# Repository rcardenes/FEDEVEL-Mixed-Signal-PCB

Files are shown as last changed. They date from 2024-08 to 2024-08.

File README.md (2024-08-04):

Mixed-Signal Demo PCB
=====================

Demo board project for the "Mixed-Signal Hardware Design with KiCAD" course, by
Phil Salmony (of Phil's Lab fame) at [FEDEVEL](fedevel.com). 

The project was created from scratch using KiCAD 8.0, following the course lectures.
It comes with all the relevant files, including missing footprints and 3D models.
Several of the 3D models were downloaded, and are not to be used without permission:

- HRO_TYPE-C-31-M-12.step (USB receptacle, from GrabCad.com)
- 31-5640-1010.stp (BNC connectors, from Amphenol.com)
- L_Coilcraft_XxL4020.step (for the matching inductor, from 3DContentCentral.com)

The models for the CMF3216 common-mode choke, and the RGB LED (E6C...) were created
by myself in FreeCAD and are free to use, with appropriate acknowledgment.

The project includes Gerber files, and BOM/Placement files. All relevant parts include
an MNP field with JCLPCB/LCSC part numbers, and the assembly files were generated using
the "Fabrication Toolkit" plugin, which generates JLCPCB-compatible output.

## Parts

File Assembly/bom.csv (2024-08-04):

Designator | Footprint | Quantity | Value | LCSC Part #
C201, C302, C303, C304, C305, C311, C312, C313, C402, C403, C404, C410, C411, C416, C503, C504 | 0402 | 16 | 100n | C1525
C202, C203, C307, C308, C507 | 0603 | 5 | 1u | C15849
C204, C205, C206, C207, C208 | 0805 | 5 | 22u | C45783
C209 | 0402 | 1 | DNP
C301, C409, C412, C413, C414, C415, C502 | 0603 | 7 | 10u | C19702
C306 | 0402 | 1 | 10nF | C15195
C309, C310 | 0402 | 2 | 10p | C32949
C401, C406, C501, C505 | 0402 | 4 | 1n | C1523
C405, C407, C408, C506 | 0402 | 4 | 150p | C106998
D201 | 0603 | 1 | RED | C2286
D301 | E6C1206RGBC3UDA | 1 | LED_RGB_E6C1206RGBC3UDA | C375571
D302, D303, D304, D305, D306, D401, D501 | D_SOD-323 | 7 | PESD3V3L1BA,115 | C51450
FL301 | CMF3216F | 1 | CMF3216F-900-2P-T | C963740
J301 | USB_C_Receptacle_HRO_TYPE-C-31-M-12 | 1 | USB_C_Receptacle_USB2.0_16P | C319148
J302 | PinHeader_2x05_P1.27mm_Vertical_SMD | 1 | 2x5x1.27mm | C920813
J401, J501 | BNC_Amphenol_B6252HB-NPP3G-50_Horizontal | 2 | DOSIN-801-0031 | C521205
L201, L301 | 0402 | 2 | 10n | C404632
L202 | L_Coilcraft_XxL4020 | 1 | 68u | C3151182
R201 | 0805 | 1 | 10R | C17415
R202, R203, R205, R308, R310, R313, R402, R406, R408 | 0402 | 9 | 1k | C11702
R204 | 0402 | 1 | 100k | 0402
R206, R404, R502 | 0402 | 3 | 22k | C25768
R301, R302, R307, R506 | 0402 | 4 | 10k | C25744
R303, R304 | 0402 | 2 | 5k1 | C25905
R305, R410, R505 | 0402 | 3 | 0R | C17168
R306 | 0402 | 1 | 1k5 | C25867
R309, R311, R312, R314, R409, R504 | 0402 | 6 | 49R9 | C25120
R401, R407 | 0402 | 2 | 2M2 | C274901
R403, R501 | 0603 | 2 | 6k8 | C23212
R405, R503 | 0402 | 2 | 12k | C25752
U201 | SOT-89-3 | 1 | HT7533-1 | C14289
U202, U401, U402, U501 | SOT-23-5 | 4 | MCP6001T-E/OT | C29429
U203 | SOT-23-5 | 1 | TLV62569DBV | C2864104
U301 | LQFP-48_7x7mm_P0.5mm | 1 | STM32F103CBT6 | C8304
U302 | SOT-23-6 | 1 | USBLC6-2SC6 | USBLC6-2SC6
U403 | VSSOP-10_3x3mm_P0.5mm | 1 | ADC141S626CIMM_NOPB | C206494
U404 | SOT-23 | 1 | REF3033A/DBZT | C2872391
U502 | VSSOP-10_3x3mm_P0.5mm | 1 | DAC7563TDGSR | C2879196
Y301 | Crystal_SMD_3225-4Pin_3.2x2.5mm | 1 | 16MHz | C362342

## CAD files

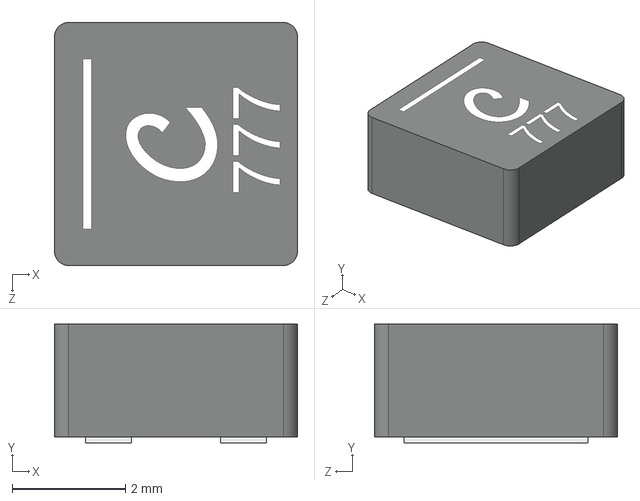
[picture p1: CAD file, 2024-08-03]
3DModels/3DContentCentral/L_Coilcraft_XxL4020.step
4.30 x 2.10 x 4.30 mm

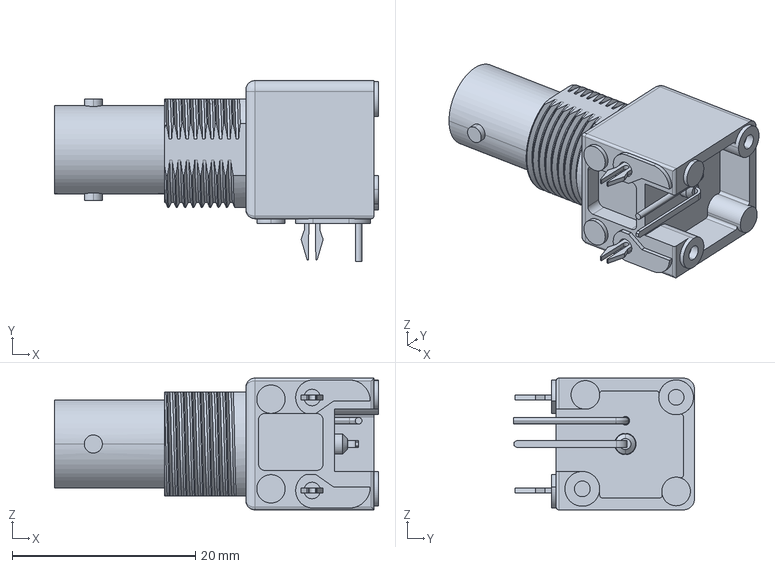
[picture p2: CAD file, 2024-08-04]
3DModels/Amphenol/31-5640-1010.stp
35.4 x 19.8 x 14.4 mm

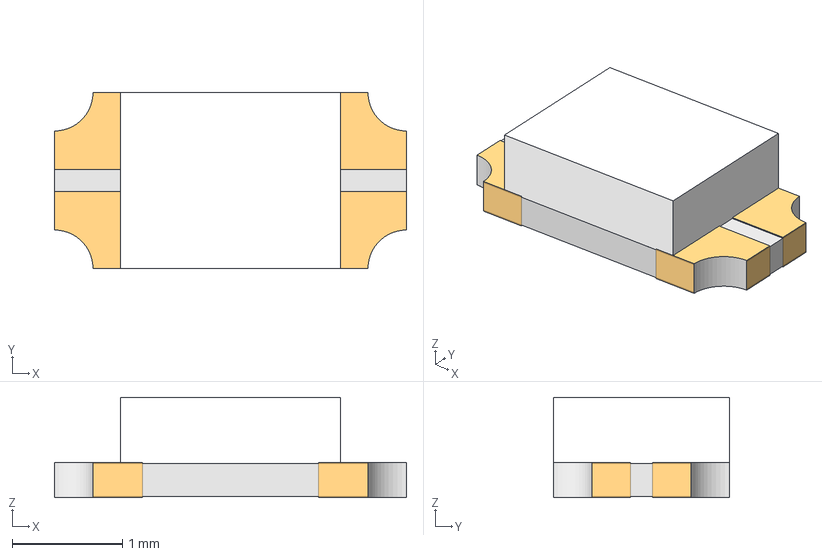
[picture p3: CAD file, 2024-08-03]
3DModels/E6C1206RGBC3UDA.step
3.20 x 1.60 x 0.91 mm

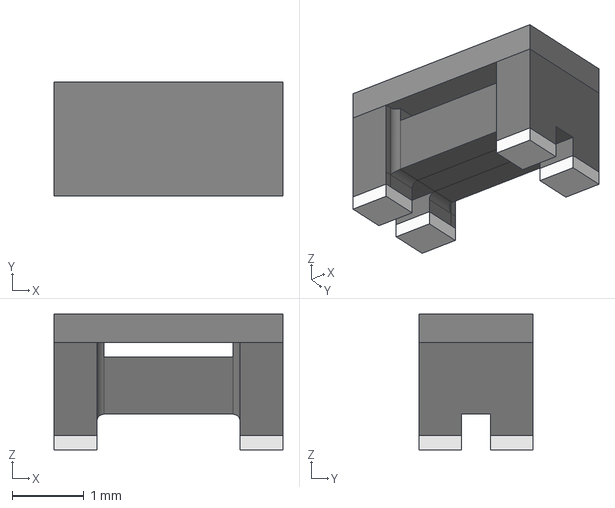
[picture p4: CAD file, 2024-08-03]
3DModels/CMF3216.step
3.20 x 1.60 x 1.90 mm

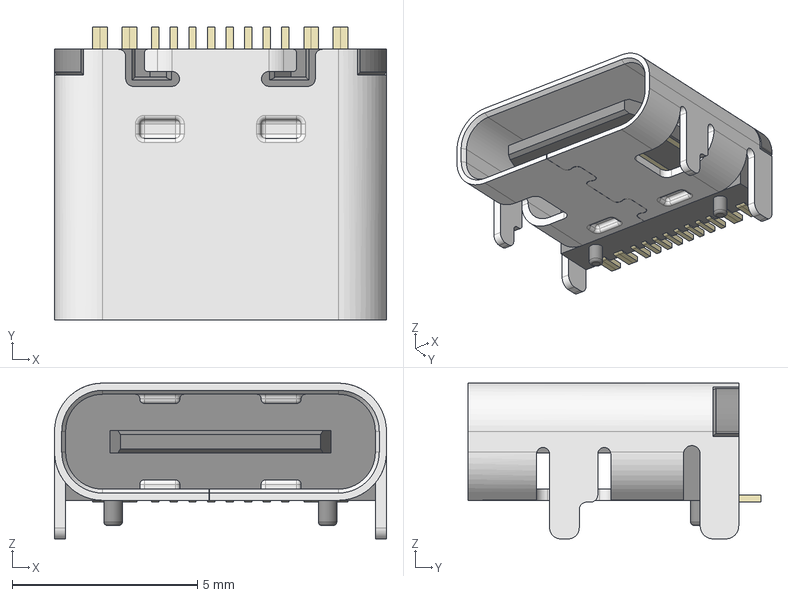
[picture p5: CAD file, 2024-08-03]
3DModels/GrabCad/HRO_TYPE-C-31-M-12.step
8.95 x 7.90 x 4.20 mm

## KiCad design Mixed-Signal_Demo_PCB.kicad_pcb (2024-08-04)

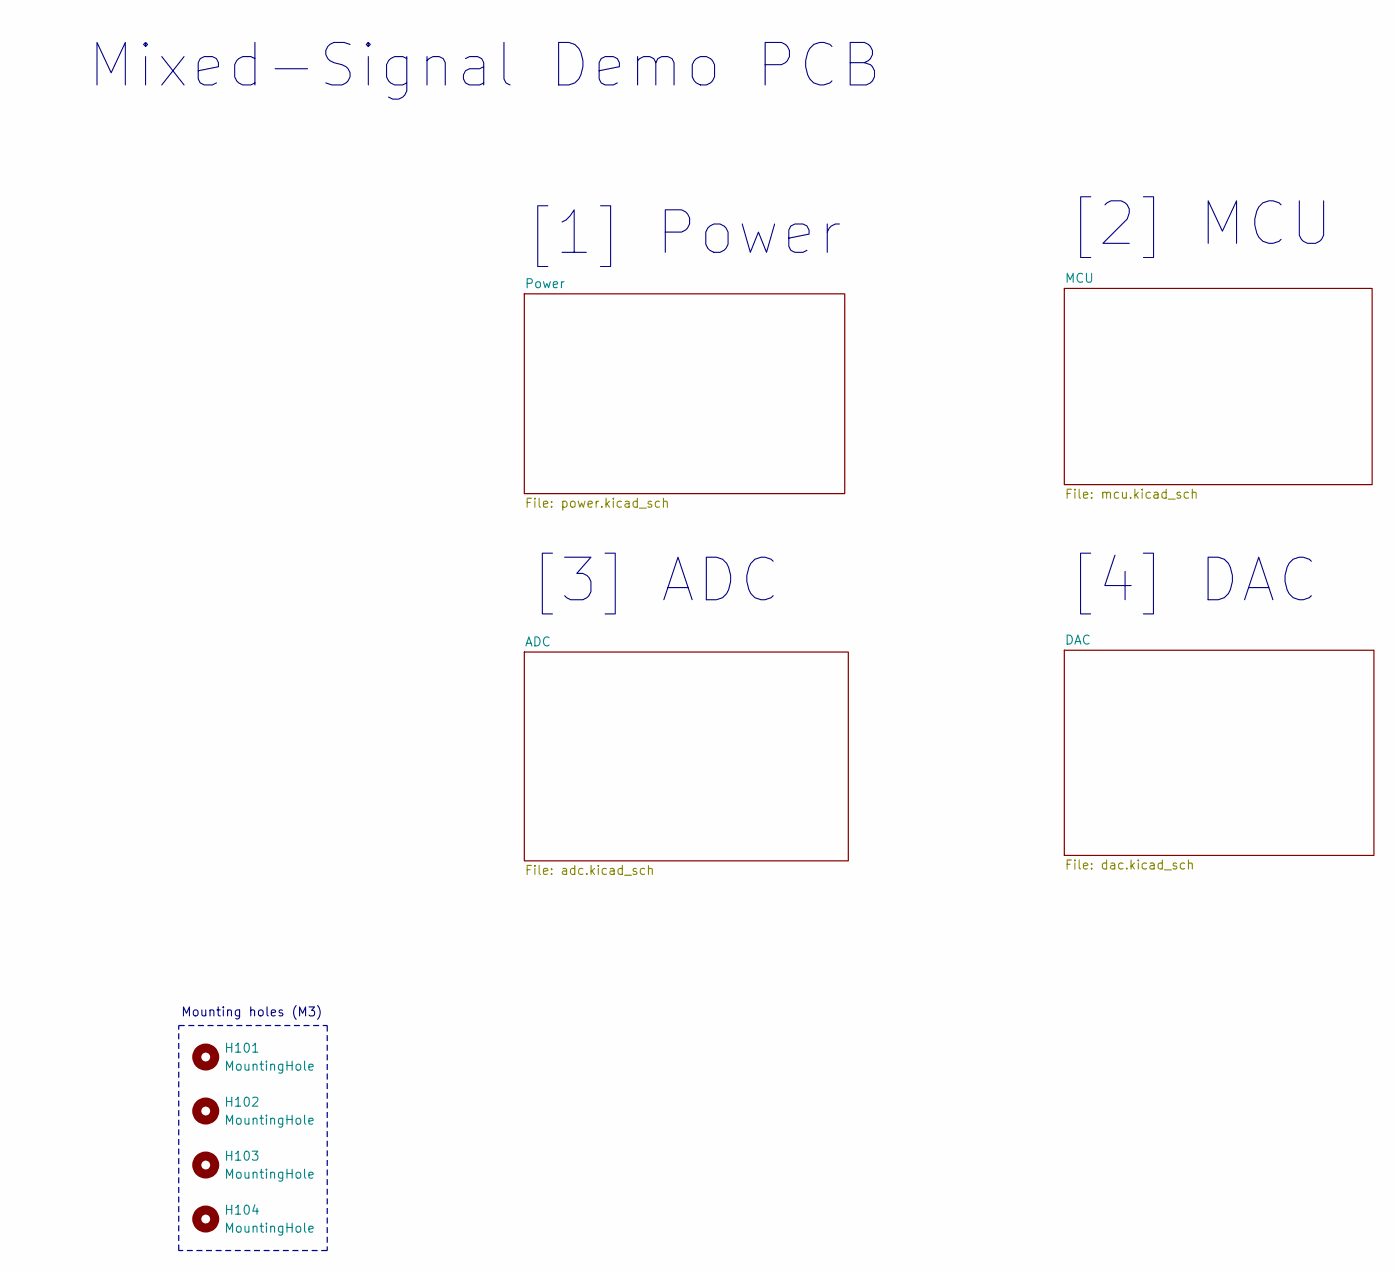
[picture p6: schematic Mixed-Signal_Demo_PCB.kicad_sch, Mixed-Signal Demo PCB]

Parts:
H101, H102, H103, H104: MountingHole; MountingHole_3.2mm_M3

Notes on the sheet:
[2] MCU
[1] Power
[3] ADC
[4] DAC
Mounting holes (M3)
Mixed-Signal Demo PCB

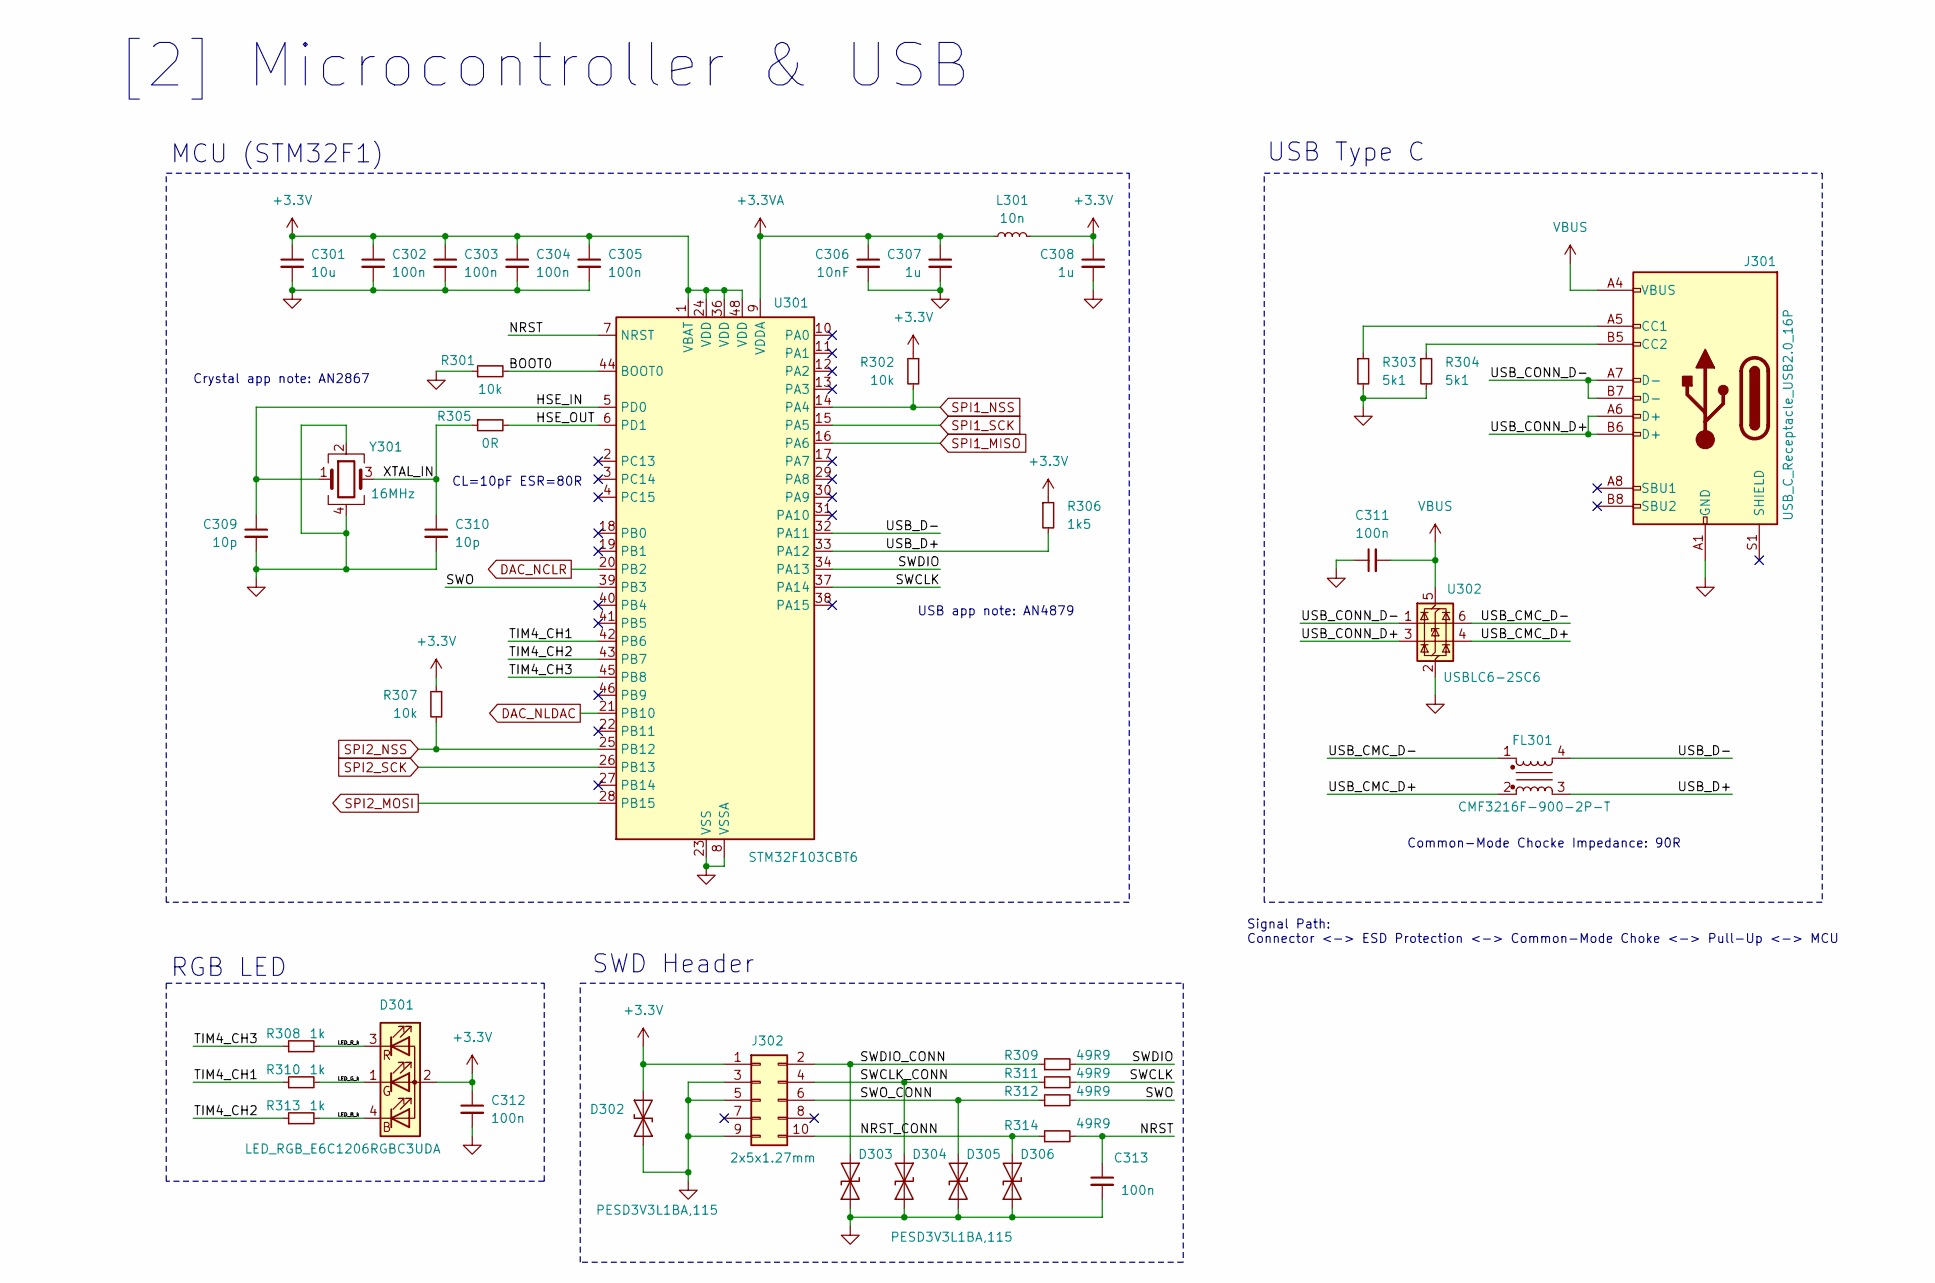
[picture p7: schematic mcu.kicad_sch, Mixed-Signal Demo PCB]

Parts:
C301: 10u; C_0603_1608Metric; MPN C19702
C302, C303, C304, C305, C311, C312, C313: 100n; C_0402_1005Metric; MPN C1525
C306: 10nF; C_0402_1005Metric; MPN C15195
C307, C308: 1u; C_0603_1608Metric; MPN C15849
C309, C310: 10p; C_0402_1005Metric; MPN C32949
D301: LED_RGB_E6C1206RGBC3UDA; E6C1206RGBC3UDA; MPN C375571
D302, D303, D304, D305, D306: PESD3V3L1BA,115; D_SOD-323; MPN C51450
FL301: CMF3216F-900-2P-T; CMF3216F; MPN C963740
J301: USB_C_Receptacle_USB2.0_16P; USB_C_Receptacle_HRO_TYPE-C-31-M-12; MPN C319148
J302: 2x5x1.27mm; PinHeader_2x05_P1.27mm_Vertical_SMD; MPN C920813
L301: 10n; L_0402_1005Metric; MPN C404632
R301, R302, R307: 10k; R_0402_1005Metric; MPN C25744
R303, R304: 5k1; R_0402_1005Metric; MPN C25905
R305: 0R; R_0402_1005Metric; MPN C17168
R306: 1k5; R_0402_1005Metric; MPN C25867
R308, R310, R313: 1k; R_0402_1005Metric; MPN C11702
R309, R311, R312, R314: 49R9; R_0402_1005Metric; MPN C25120
U301: STM32F103CBT6; LQFP-48_7x7mm_P0.5mm; MPN C8304
U302: USBLC6-2SC6; SOT-23-6; MPN USBLC6-2SC6
Y301: 16MHz; Crystal_SMD_3225-4Pin_3.2x2.5mm; MPN C362342

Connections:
+3.3V: C301.1, C302.1, C303.1, C304.1, C305.1, C308.1, C312.1, D301.2 (A), D302.2 (A2), J302.1, L301.2, R302.1, R306.1, R307.1, U301.1 (VBAT), U301.24 (VDD), U301.36 (VDD), U301.48 (VDD); also elsewhere on the board
+3.3VA: C306.1, C307.1, L301.1, U301.9 (VDDA); also elsewhere on the board
/MCU/BOOT0: R301.2, U301.44 (BOOT0)
/MCU/HSE_IN: C309.1, U301.5 (PD0), Y301.1
/MCU/HSE_OUT: R305.2, U301.6 (PD1)
/MCU/LED_B_k: D301.4 (BK), R313.2
/MCU/LED_G_k: D301.1 (GK), R310.2
/MCU/LED_R_k: D301.3 (RK), R308.2
/MCU/NRST: C313.1, R314.2, U301.7 (NRST)
/MCU/NRST_CONN: D306.2 (A2), J302.10, R314.1
/MCU/SWCLK: R311.2, U301.37 (PA14)
/MCU/SWCLK_CONN: D304.2 (A2), J302.4, R311.1
/MCU/SWDIO: R309.2, U301.34 (PA13)
/MCU/SWDIO_CONN: D303.2 (A2), J302.2, R309.1
/MCU/SWO: R312.2, U301.39 (PB3)
/MCU/SWO_CONN: D305.2 (A2), J302.6, R312.1
/MCU/TIM4_CH1: R310.1, U301.42 (PB6)
/MCU/TIM4_CH2: R313.1, U301.43 (PB7)
/MCU/TIM4_CH3: R308.1, U301.45 (PB8)
/MCU/USB_CMC_D+: FL301.2, U302.4 (I/O2)
/MCU/USB_CMC_D-: FL301.1, U302.6 (I/O1)
/MCU/USB_CONN_D+: J301.A6 (D+), J301.B6 (D+), U302.3 (I/O2)
/MCU/USB_CONN_D-: J301.A7 (D-), J301.B7 (D-), U302.1 (I/O1)
/MCU/USB_D+: FL301.3, R306.2, U301.33 (PA12)
/MCU/USB_D-: FL301.4, U301.32 (PA11)
/MCU/XTAL_IN: C310.1, R305.1, Y301.3
DAC_NCLR: U301.20 (PB2); also elsewhere on the board
DAC_NLDAC: U301.21 (PB10); also elsewhere on the board
GND: C301.2, C302.2, C303.2, C304.2, C305.2, C306.2, C307.2, C308.2, C309.2, C310.2, C311.1, C312.2, C313.2, D302.1 (A1), D303.1 (A1), D304.1 (A1), D305.1 (A1), D306.1 (A1), J301.A1 (GND), J301.A12 (GND), J301.B1 (GND), J301.B12 (GND), J302.3, J302.5, J302.9, R301.1, R303.2, R304.2, U301.8 (VSSA), U301.23 (VSS), U301.35 (VSS), U301.47 (VSS), U302.2 (GND), Y301.2, Y301.4; also elsewhere on the board
unnamed: J301.A5 (CC1), R303.1
unnamed: J301.B5 (CC2), R304.1
SPI1_MISO: U301.16 (PA6); also elsewhere on the board
SPI1_NSS: R302.2, U301.14 (PA4); also elsewhere on the board
SPI1_SCK: U301.15 (PA5); also elsewhere on the board
SPI2_MOSI: U301.28 (PB15); also elsewhere on the board
SPI2_NSS: R307.2, U301.25 (PB12); also elsewhere on the board
SPI2_SCK: U301.26 (PB13); also elsewhere on the board
VBUS: C311.2, J301.A4 (VBUS), J301.A9 (VBUS), J301.B4 (VBUS), J301.B9 (VBUS), U302.5 (VBUS); also elsewhere on the board

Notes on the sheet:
MCU (STM32F1)
[2] Microcontroller & USB
RGB LED
SWD Header
Crystal app note: AN2867
CL=10pF ESR=80R
Signal Path: Connector <-> ESD Protection <-> Common-Mode Choke <-> Pull-Up <-> MCU
USB app note: AN4879
Common-Mode Chocke Impedance: 90R
USB Type C

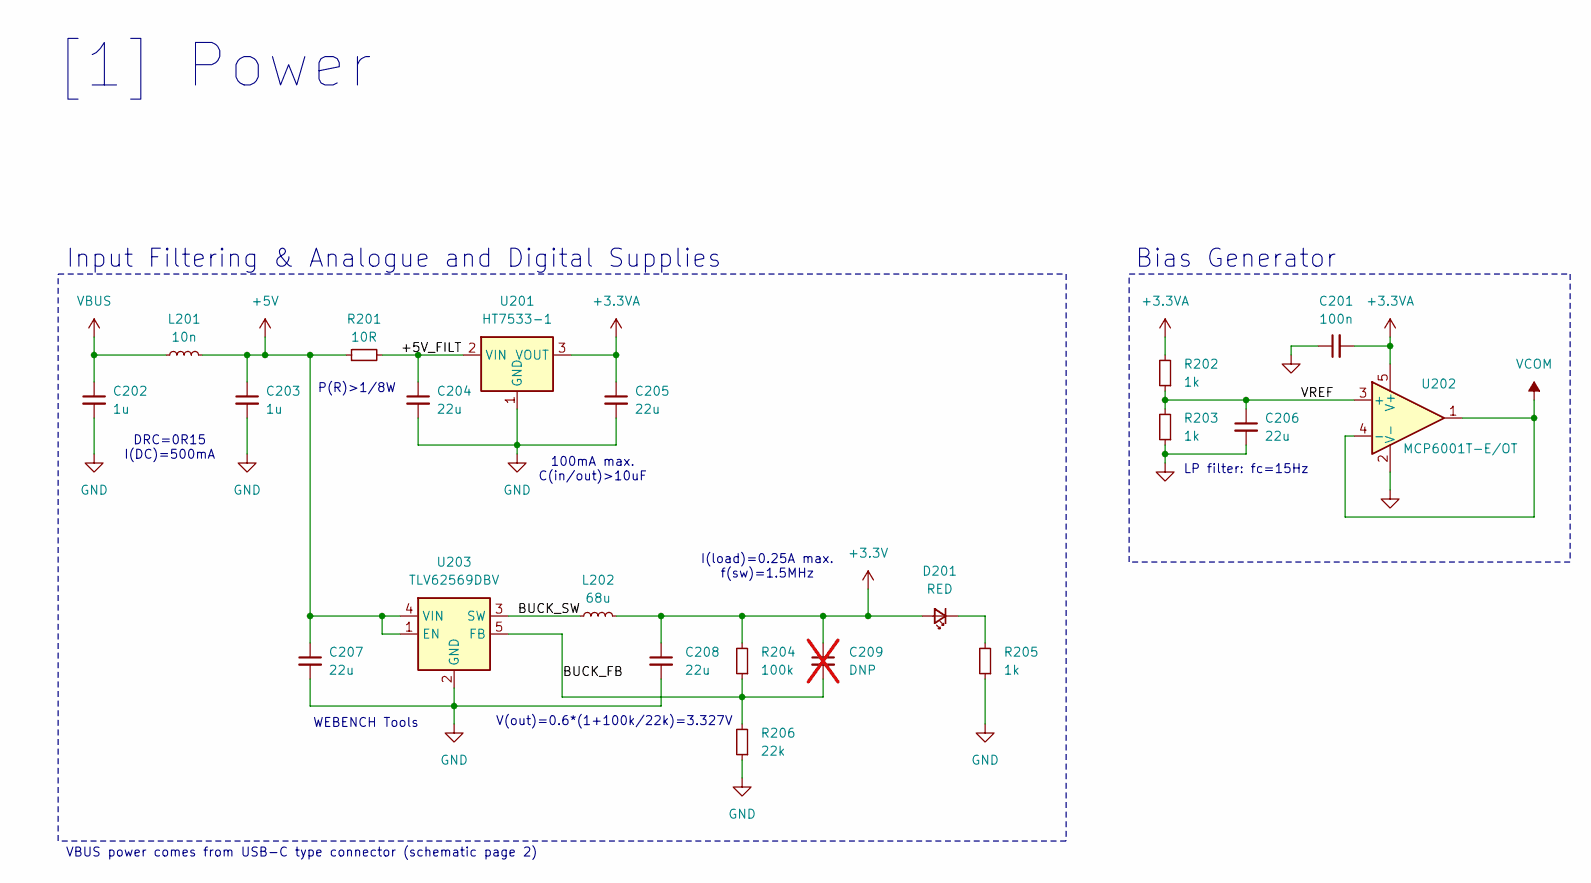
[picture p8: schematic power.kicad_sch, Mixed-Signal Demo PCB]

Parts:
C201: 100n; C_0402_1005Metric; MPN C1525
C202, C203: 1u; C_0603_1608Metric; MPN C15849
C204, C205, C206, C207, C208: 22u; C_0805_2012Metric; MPN C45783
C209: DNP; C_0402_1005Metric; not fitted
D201: RED; LED_0603_1608Metric; MPN C2286
L201: 10n; L_0402_1005Metric; MPN C404632
L202: 68u; L_Coilcraft_XxL4020; MPN C3151182
R201: 10R; R_0805_2012Metric; MPN C17415
R202, R203, R205: 1k; R_0402_1005Metric; MPN C11702
R204: 100k; R_0402_1005Metric; MPN 0402
R206: 22k; R_0402_1005Metric; MPN C25768
U201: HT7533-1; SOT-89-3; MPN C14289
U202: MCP6001T-E/OT; SOT-23-5; MPN C29429
U203: TLV62569DBV; SOT-23-5; MPN C2864104

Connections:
+3.3V: C208.1, C209.1, D201.2 (A), L202.2, R204.2; also elsewhere on the board
+3.3VA: C201.2, C205.1, R202.2, U201.3 (VOUT), U202.5 (V+); also elsewhere on the board
+5V: C203.1, C207.1, L201.2, R201.1, U203.1 (EN), U203.4 (VIN); also elsewhere on the board
/Power/+5V_FILT: C204.1, R201.2, U201.2 (VIN)
/Power/BUCK_FB: C209.2, R204.1, R206.2, U203.5 (FB)
/Power/BUCK_SW: L202.1, U203.3 (SW)
/Power/VREF: C206.1, R202.1, R203.2, U202.3 (+)
GND: C201.1, C202.2, C203.2, C204.2, C205.2, C206.2, C207.2, C208.2, R203.1, R205.1, R206.1, U201.1 (GND), U202.2 (V-), U203.2 (GND); also elsewhere on the board
unnamed: D201.1 (K), R205.2
VBUS: C202.1, L201.1; also elsewhere on the board
VCOM: U202.1, U202.4 (-); also elsewhere on the board

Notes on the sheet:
100mA max. C(in/out)>10uF
I(load)=0.25A max. f(sw)=1.5MHz
Bias Generator
DRC=0R15 I(DC)=500mA
P(R)>1/8W
LP filter: fc=15Hz
V(out)=0.6*(1+100k/22k)=3.327V
VBUS power comes from USB-C type connector (schematic page 2)
[1] Power
WEBENCH Tools
Input Filtering & Analogue and Digital Supplies

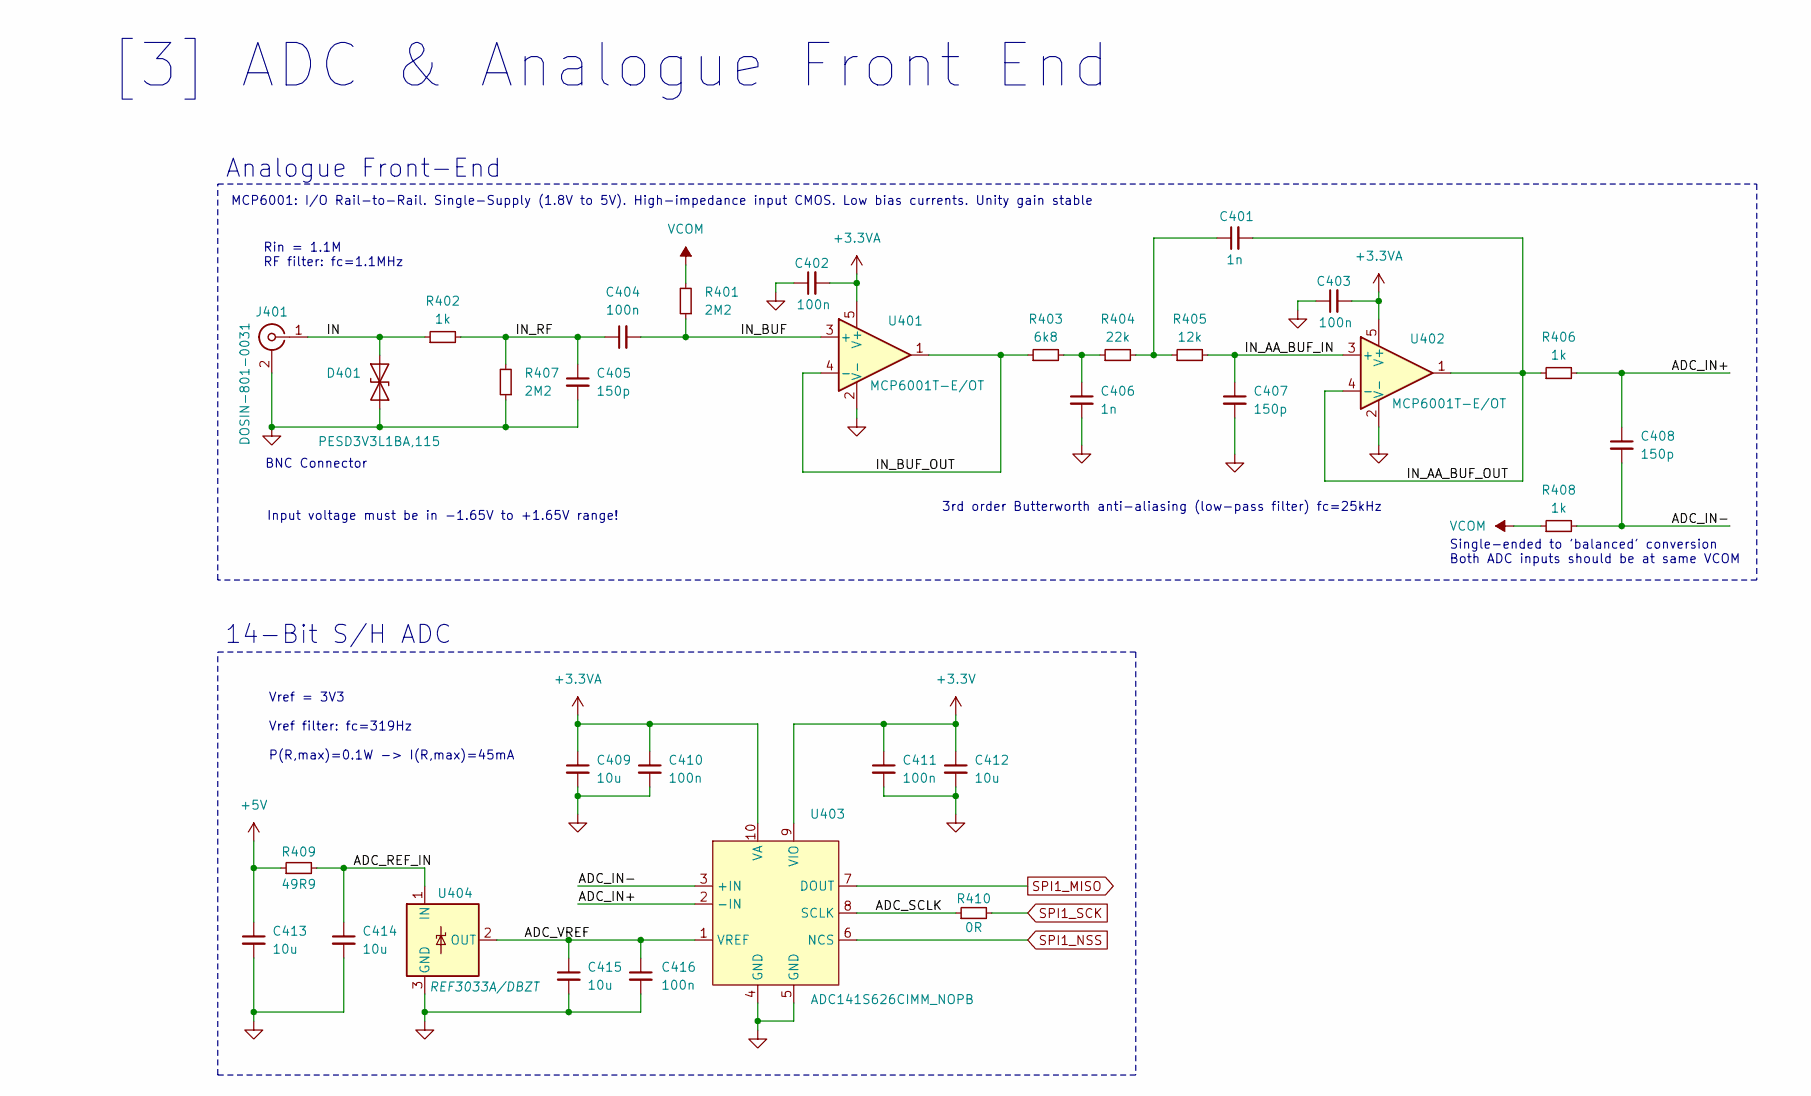
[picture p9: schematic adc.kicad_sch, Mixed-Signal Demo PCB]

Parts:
C401, C406: 1n; C_0402_1005Metric; MPN C1523
C402, C403, C404, C410, C411, C416: 100n; C_0402_1005Metric; MPN C1525
C405, C407, C408: 150p; C_0402_1005Metric; MPN C106998
C409, C412, C413, C414, C415: 10u; C_0603_1608Metric; MPN C19702
D401: PESD3V3L1BA,115; D_SOD-323; MPN C51450
J401: DOSIN-801-0031; BNC_Amphenol_B6252HB-NPP3G-50_Horizontal; MPN C521205
R401, R407: 2M2; R_0402_1005Metric; MPN C274901
R402, R406, R408: 1k; R_0402_1005Metric; MPN C11702
R403: 6k8; R_0603_1608Metric; MPN C23212
R404: 22k; R_0402_1005Metric; MPN C25768
R405: 12k; R_0402_1005Metric; MPN C25752
R409: 49R9; R_0402_1005Metric; MPN C25120
R410: 0R; R_0402_1005Metric; MPN C17168
U401, U402: MCP6001T-E/OT; SOT-23-5; MPN C29429
U403: ADC141S626CIMM_NOPB; VSSOP-10_3x3mm_P0.5mm; MPN C206494
U404: REF3033A/DBZT; SOT-23; MPN C2872391

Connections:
+3.3V: C411.1, C412.1, U403.9 (VIO); also elsewhere on the board
+3.3VA: C402.2, C403.2, C409.1, C410.1, U401.5 (V+), U402.5 (V+), U403.10 (VA); also elsewhere on the board
+5V: C413.1, R409.1; also elsewhere on the board
/ADC/ADC_IN+: C408.1, R406.2, U403.2 (-IN)
/ADC/ADC_IN-: C408.2, R408.2, U403.3 (+IN)
/ADC/ADC_REF_IN: C414.1, R409.2, U404.1 (IN)
/ADC/ADC_SCLK: R410.1, U403.8 (SCLK)
/ADC/ADC_VREF: C415.1, C416.1, U403.1 (VREF), U404.2 (OUT)
/ADC/IN: D401.2 (A2), J401.1 (In), R402.1
/ADC/IN_AA_BUF_IN: C407.1, R405.2, U402.3 (+)
/ADC/IN_AA_BUF_OUT: C401.2, R406.1, U402.1, U402.4 (-)
/ADC/IN_BUF: C404.2, R401.1, U401.3 (+)
/ADC/IN_BUF_OUT: R403.1, U401.1, U401.4 (-)
/ADC/IN_RF: C404.1, C405.1, R402.2, R407.2
GND: C402.1, C403.1, C405.2, C406.2, C407.2, C409.2, C410.2, C411.2, C412.2, C413.2, C414.2, C415.2, C416.2, D401.1 (A1), J401.2 (Ext), R407.1, U401.2 (V-), U402.2 (V-), U403.4 (GND), U403.5 (GND), U404.3 (GND); also elsewhere on the board
unnamed: C401.1, R404.2, R405.1
unnamed: C406.1, R403.2, R404.1
SPI1_MISO: U403.7 (DOUT); also elsewhere on the board
SPI1_NSS: U403.6 (NCS); also elsewhere on the board
SPI1_SCK: R410.2; also elsewhere on the board
VCOM: R401.2, R408.1; also elsewhere on the board

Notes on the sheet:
[3] ADC & Analogue Front End
MCP6001: I/O Rail-to-Rail. Single-Supply (1.8V to 5V). High-impedance input CMOS. Low bias currents. Unity gain stable
Input voltage must be in -1.65V to +1.65V range!
Analogue Front-End
3rd order Butterworth anti-aliasing (low-pass filter) fc=25kHz
Single-ended to 'balanced' conversion Both ADC inputs should be at same VCOM
Rin = 1.1M RF filter: fc=1.1MHz
BNC Connector
14-Bit S/H ADC
Vref = 3V3 Vref filter: fc=319Hz P(R,max)=0.1W -> I(R,max)=45mA

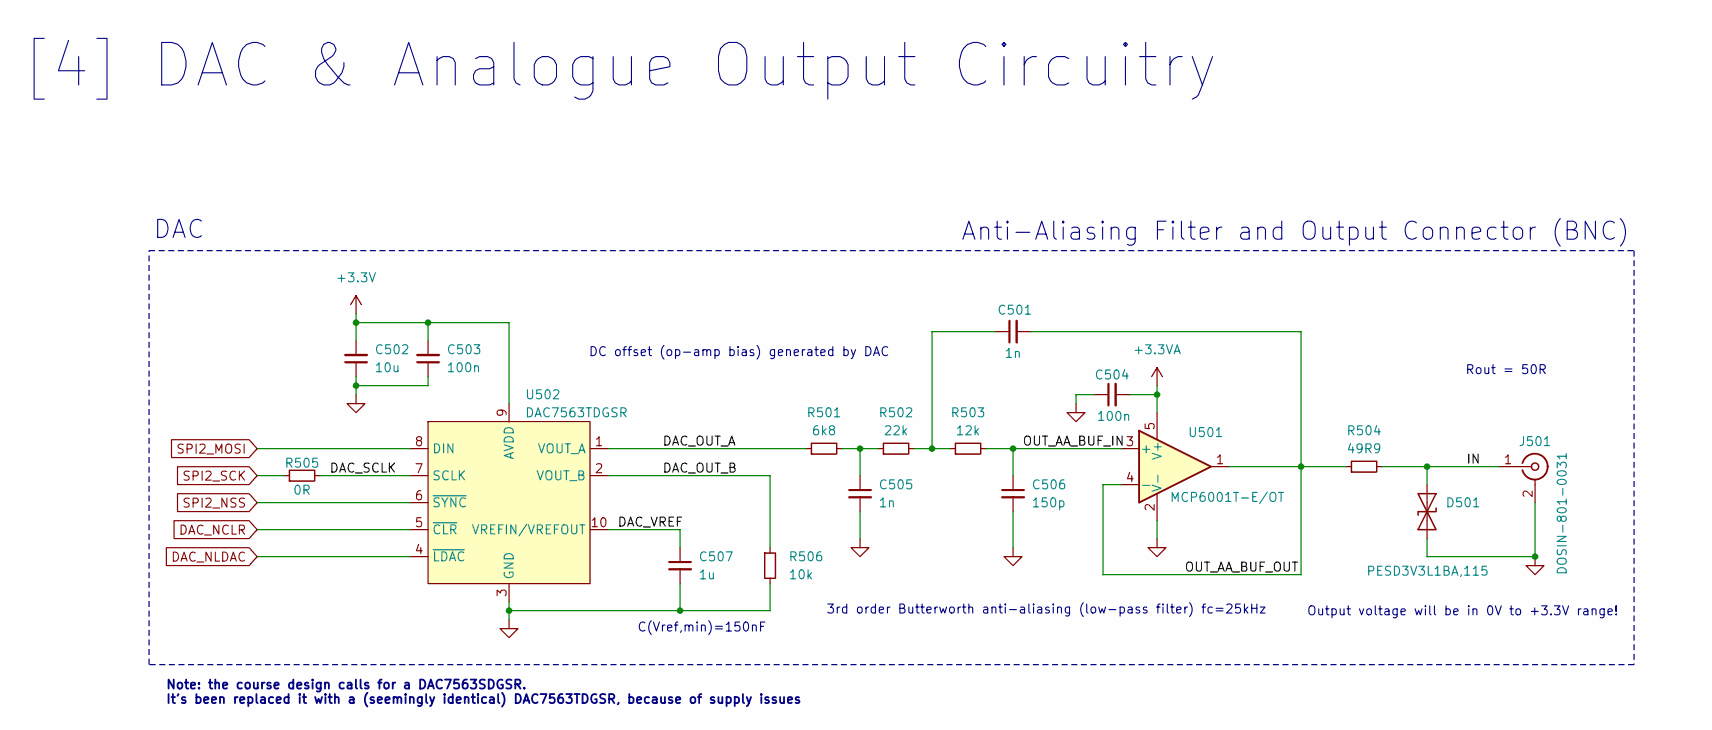
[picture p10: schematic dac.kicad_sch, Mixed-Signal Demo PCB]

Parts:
C501, C505: 1n; C_0402_1005Metric; MPN C1523
C502: 10u; C_0603_1608Metric; MPN C19702
C503, C504: 100n; C_0402_1005Metric; MPN C1525
C506: 150p; C_0402_1005Metric; MPN C106998
C507: 1u; C_0603_1608Metric; MPN C15849
D501: PESD3V3L1BA,115; D_SOD-323; MPN C51450
J501: DOSIN-801-0031; BNC_Amphenol_B6252HB-NPP3G-50_Horizontal; MPN C521205
R501: 6k8; R_0603_1608Metric; MPN C23212
R502: 22k; R_0402_1005Metric; MPN C25768
R503: 12k; R_0402_1005Metric; MPN C25752
R504: 49R9; R_0402_1005Metric; MPN C25120
R505: 0R; R_0402_1005Metric; MPN C17168
R506: 10k; R_0402_1005Metric; MPN C25744
U501: MCP6001T-E/OT; SOT-23-5; MPN C29429
U502: DAC7563TDGSR; VSSOP-10_3x3mm_P0.5mm; MPN C2879196

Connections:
+3.3V: C502.2, C503.2, U502.9 (AVDD); also elsewhere on the board
+3.3VA: C504.2, U501.5 (V+); also elsewhere on the board
/DAC/DAC_OUT_A: R501.1, U502.1 (VOUT_A)
/DAC/DAC_OUT_B: R506.1, U502.2 (VOUT_B)
/DAC/DAC_SCLK: R505.2, U502.7 (SCLK)
/DAC/DAC_VREF: C507.1, U502.10 (VREFIN/VREFOUT)
/DAC/IN: D501.2 (A2), J501.1 (In), R504.2
/DAC/OUT_AA_BUF_IN: C506.1, R503.2, U501.3 (+)
/DAC/OUT_AA_BUF_OUT: C501.2, R504.1, U501.1, U501.4 (-)
DAC_NCLR: U502.5 (~CLR); also elsewhere on the board
DAC_NLDAC: U502.4 (~LDAC); also elsewhere on the board
GND: C502.1, C503.1, C504.1, C505.2, C506.2, C507.2, D501.1 (A1), J501.2 (Ext), R506.2, U501.2 (V-), U502.3 (GND); also elsewhere on the board
unnamed: C501.1, R502.2, R503.1
unnamed: C505.1, R501.2, R502.1
SPI2_MOSI: U502.8 (DIN); also elsewhere on the board
SPI2_NSS: U502.6 (~SYNC); also elsewhere on the board
SPI2_SCK: R505.1; also elsewhere on the board

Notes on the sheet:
C(Vref,min)=150nF
3rd order Butterworth anti-aliasing (low-pass filter) fc=25kHz
[4] DAC & Analogue Output Circuitry
Anti-Aliasing Filter and Output Connector (BNC)
Note: the course design calls for a DAC7563SDGSR. It's been replaced it with a (seemingly identical) DAC7563TDGSR, because of supply issues
Rout = 50R
DAC
Output voltage will be in 0V to +3.3V range!
DC offset (op-amp bias) generated by DAC

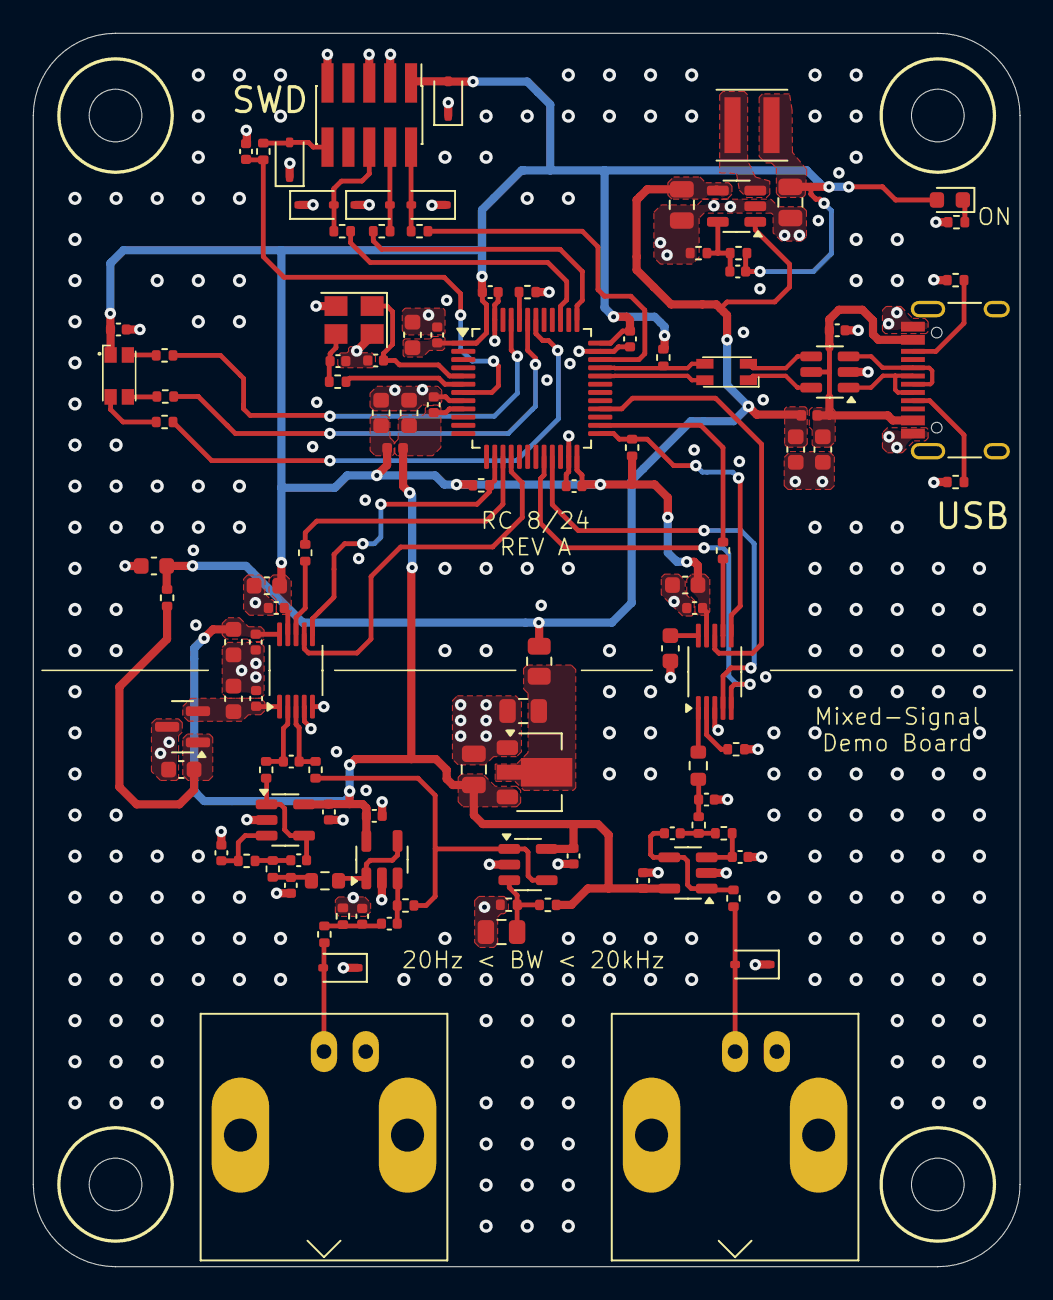
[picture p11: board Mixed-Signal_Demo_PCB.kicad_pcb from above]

Board: 4 copper layers, 60.0 x 75.0 mm, 114 parts (0 on the bottom side), 67 nets.

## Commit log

2024-07-31 Lesson 5: top level schematic + power module
    [Mixed-Signal_Demo_PCB.kicad_pcb, Mixed-Signal_Demo_PCB.kicad_sch, adc.kicad_sch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]
2024-07-31 Reannotate based on sheet page number
    [power.kicad_sch]
2024-07-31 Lesson 6: MCU and USB module
    [mcu.kicad_sch, power.kicad_sch]
2024-07-31 Lesson 7: ADC, DAC, and frontends
    [adc.kicad_sch, dac.kicad_sch]
2024-08-01 Lesson 8: Reannotation, running ERC for schematic
    [adc.kicad_sch, dac.kicad_sch, mcu.kicad_sch]
2024-08-01 Lesson 8: Assigned most footprints. Added missing ones
    [adc.kicad_sch, dac.kicad_sch, mcu.kicad_sch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]
2024-08-02 Lesson 11: Adjusted capacitor footprints and set up PCB defaults
    [Mixed-Signal_Demo_PCB.kicad_pcb, adc.kicad_sch, dac.kicad_sch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]
2024-08-02 Lesson 12: MCU and USB rough placement
    [Mixed-Signal_Demo_PCB.kicad_pcb, mcu.kicad_sch]
2024-08-02 Lesson 12: ADC and DAC
    [Mixed-Signal_Demo_PCB.kicad_pcb, adc.kicad_sch, dac.kicad_sch]
2024-08-03 Lesson 12: Rest of placement, some rearrangements. Added models
    [CMF3216.step, E6C1206RGBC3UDA.step, HRO_TYPE-C-31-M-12.step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]
2024-08-03 Lesson 13: Routing
    [Mixed-Signal_Demo_PCB.kicad_pcb, adc.kicad_sch, mcu.kicad_sch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]
2024-08-03 Lesson 14: Finishing touches
    [Mixed-Signal_Demo_PCB.kicad_pcb]
2024-08-04 Manufacture: Add part numbers
    [31-5640-1010.stp]
2024-08-04 Assembly files
    [Mixed-Signal_Demo_PCB-B_Cu.gbl, Mixed-Signal_Demo_PCB-B_Mask.gbs, Mixed-Signal_Demo_PCB-B_Paste.gbp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]
2024-08-04 Add README.md
    [Mixed-Signal_Demo_PCB.kicad_pcb]
